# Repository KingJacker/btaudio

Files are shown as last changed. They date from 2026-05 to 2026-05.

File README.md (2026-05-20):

# btaudio — Audiophiles Bluetooth 5.1 Upgrade-Board für Kopfhörer

Ein kompromissloses Wireless-Upgrade-Modul für Kabelkopfhörer. Kein All-in-One-Kompromiss — stattdessen drei dedizierte Stufen für maximale Klangqualität ohne Hintergrundrauschen.

## Architektur

```
QCC5125 (BT 5.1)  →[I2S]→  PCM5102A (DAC)  →[Analog]→  TPA6132A2 (Amp)  →  Kopfhörer
   Empfang                    Wandlung                     Verstärkung
```

**Stufe 1 — Empfang:** QCC5125 empfängt High-Res-Audio via aptX HD / LDAC und gibt das Signal rein digital (I2S) weiter. Keine Funkstörungen im Analogpfad.

**Stufe 2 — Wandlung:** PCM5102A (High-End-DAC) wandelt das I2S-Signal in ein sauberes analoges Audiosignal. Dedizierter Chip statt integriertem DAC-Billigst-Lösung.

**Stufe 3 — Verstärkung:** TPA6132A2 treibt die Kopfhörer direkt an ("Capless"-Design) — keine Elektrolytkondensatoren im Signalweg, die den Klang verfärben.

## Schaltplan

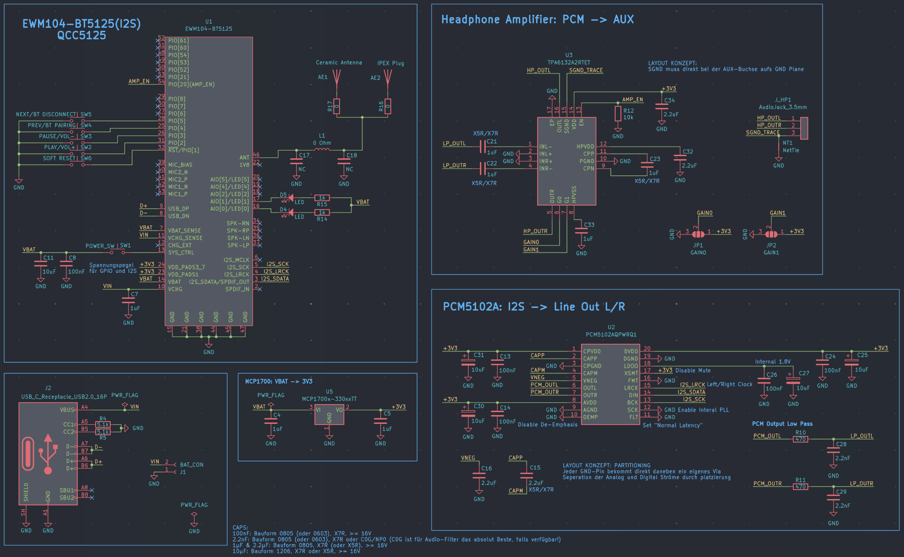
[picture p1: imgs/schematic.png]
Schaltplan


## Platine (3D-Ansicht)

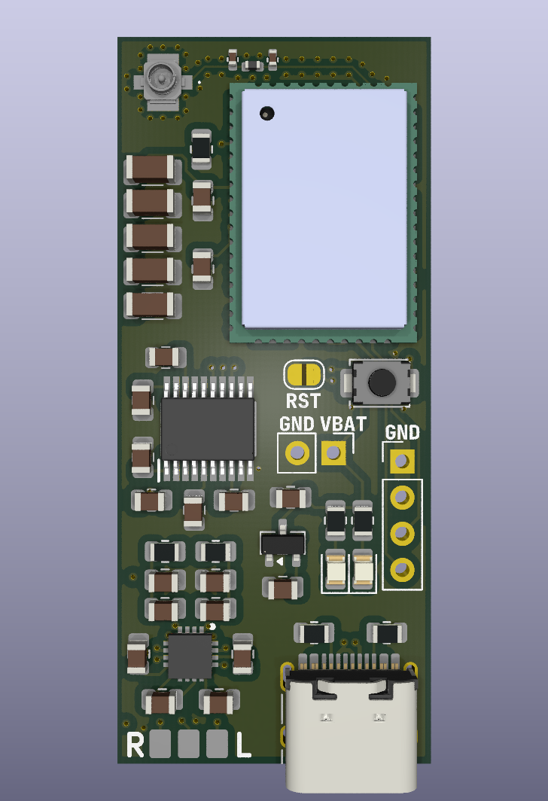
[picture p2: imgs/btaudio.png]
PCB 3D-Render


## Ziel

Alte, hochwertige Kabelkopfhörer auf modernes audiophiles Bluetooth-Niveau heben — durch konsequente Trennung von Funk, DA-Wandlung und Verstärkung.

## Hardware

- **BT-Modul:** Qualcomm QCC5125 (Bluetooth 5.1, aptX HD, LDAC)
- **DAC:** Texas Instruments PCM5102A
- **Amp:** Texas Instruments TPA6132A2 (Capless Headphone Amp)
- **Design-Tool:** KiCad

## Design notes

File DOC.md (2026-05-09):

***

# Projekt-Dokumentation: Audiophiles Bluetooth 5.1 Kopfhörer-Modul

## 1. Projektübersicht & Architektur
Das Ziel dieses Projekts ist die Entwicklung eines eigenen Carrier-Boards (Trägerplatine), um einen alten Kopfhörer mit modernem Bluetooth 5.1 auszustatten. Anstatt diskrete Bluetooth-SoCs zu verwenden (die oft hinter NDAs versteckt oder schwer zu löten sind), wird ein **System-on-Module (SoM)** Ansatz gewählt.

Um die höchste Audioqualität ohne störendes Hintergrundrauschen (oft durch das RF-Signal verursacht) zu erreichen, nutzt das Design eine strikt getrennte, audiophile Architektur:
**Bluetooth-Modul (Digital I2S) $\rightarrow$ Separater I2S-DAC $\rightarrow$ Dedizierter Kopfhörerverstärker.**

## 2. Die Wahl des Bluetooth-Moduls: EBYTE EWM104-BT5125(I2S)
Nach der Analyse des Datenblattes fiel die Wahl auf das EBYTE-Modul basierend auf dem **Qualcomm QCC5125** Chip.
*   **Warum QCC5125?** Unterstützt echtes Stereo, Bluetooth 5.1 und High-End-Codecs wie aptX-HD und LDAC. (Der günstigere QCC3040 ist bei diesem Hersteller nur für Mono/TWS konfiguriert).
*   **Warum die I2S-Variante?** Das Modul gibt ein rein digitales I2S-Signal aus. Die (DAC)-Variante des Moduls würde ein differentielles Analogsignal ausgeben, was zwingend einen externen Differenzverstärker erfordern würde und anfälliger für Rauschen ist.
*   **Vorteil:** Das Modul bringt bereits einen Laderegler für den Li-Po-Akku mit!

## 3. Die drei Kern-Blöcke der Schaltung

### 3.1 Die Audio-Stufe ("DirectPath / Capless")
*   **DAC (TI PCM5102A):** Wandelt das digitale I2S-Signal in ein sauberes analoges Line-Signal. Generiert seinen Systemtakt (MCLK) intern und benötigt nur wenige externe Bauteile.
*   **Verstärker (TI TPA6132A2 / MAX97220):** Liefert den nötigen Strom für typische 32-Ohm Kopfhörertreiber, um einen satten Bass zu garantieren.
*   *Architektur-Vorteil:* Beide ICs besitzen interne Charge-Pumps zur Erzeugung einer negativen Versorgungsspannung. Dadurch entfallen große DC-Blocking-Kondensatoren am Audioausgang, die den Klang verfälschen würden.

### 3.2 Stromversorgung & USB-C
*   Der Akku wird direkt an den `VBAT`-Pin des EBYTE-Moduls angeschlossen.
*   Die 5V-Spannung der USB-C Buchse geht an den `VCHG`-Pin des Moduls (internes BMS lädt den Akku).
*   Für die modernen USB-C Power Delivery Netzteile müssen die Pins `CC1` und `CC2` der Buchse über jeweils einen **$5.1\,\text{k}\Omega$ Widerstand auf GND** gezogen werden.
*   Ein extrem rauscharmer LDO-Regler macht aus der schwankenden Akkuspannung (3.0 - 4.2V) perfekte **3.3V** für den Audio-DAC und den Verstärker.

### 3.3 Hochfrequenz (RF) & Antennendesign
Das EBYTE-Modul besitzt keine integrierte Antenne (Stamp-Hole).
*   Vom Modul-Pin `ANT` wird eine exakt **$50\,\Omega$ impedanzkontrollierte Leiterbahn** zu einer SMD-Keramikantenne geroutet.
*   In Serie wird ein $0\,\Omega$ Widerstand als Brücke / Platzhalter für ein mögliches Matching-Netzwerk platziert.

---

## 4. Bill of Materials (BOM) / Stückliste

| Kategorie | Bauteil / Funktion | Empfohlene(r) Typ(en) / Partnummer | Bauform | Stk. | Anmerkung / Aufgabe im Schaltplan |
| :--- | :--- | :--- | :--- | :--- | :--- |
| **Funk / Core** | **Bluetooth SoM** | EBYTE EWM104-BT5125(I2S) | Stamp Hole | 1 | Das Gehirn; liefert digitales Audio (I2S) & lädt den Akku. |
| | **Keramik-Antenne** | Johanson 2450AT18A100E *oder* Yageo | SMD 0603/1206 | 1 | 2.4 GHz Chip-Antenne (vermeidet komplexes PCB-Antennendesign). |
| | **RF-Matching** | $0\,\Omega$ Widerstand | SMD 0603 | 1 | Brücke in Serie zwischen Modul-Pin `ANT` und Antenne. |
| **Audio** | **I2S Audio-DAC** | **Texas Instruments PCM5102A** | TSSOP-20 | 1 | Wandelt I2S (digital) exzellent in analoges Line-Signal um. |
| | **Kopfhörer-Amp** | **TI TPA6132A2** *oder* **Maxim MAX97220** | WQFN / TDFN | 1 | Capless-Verstärker; liefert den nötigen Strom für satte Bässe. |
| | **Audio-Buchse** | 3.5mm Klinkenbuchse (z.B. PJ-320D) | SMD oder THT | 1 | Optional; Kopfhörerkabel können auch direkt verlötet werden. |
| **Power** | **USB-C Buchse** | 6-Pin oder 16-Pin Type-C | SMD | 1 | Ladeanschluss; 5V gehen an Pin 10 (`VCHG`) des Moduls. |
| | **PD-Widerstände** | $5.1\,\text{k}\Omega$ Widerstand | SMD 0603 | 2 | Zwingend an `CC1` & `CC2` (gegen GND) für USB-C Erkennung. |
| | **Li-Po Akku** | 3.7V, ca. 300 - 500 mAh mit BMS | JST-Stecker | 1 | Spannungsquelle; an Pin 14 (`VBAT`) und `GND`. |
| | **3.3V LDO-Regler** | TI TPS7A2033 *oder* MIC5219-3.3YM5 | SOT-23-5 | 1 | Rauscharme 3.3V für DAC, Amp & IO-Signale. |
| **Interface** | **Taster**| Standard Tactile Switch (Drucktaster) | SMD | 4 | Play/Pause, Vol+, Vol- und Power/Pairing. |
| | **Status LEDs** | LED Rot & LED Blau | SMD 0603 | 2 | Für Systemstatus. |
| | **LED-Widerstände** | ca. $470\,\Omega$ bis $1\,\text{k}\Omega$ | SMD 0603 | 2 | Strombegrenzung für die LEDs. |
| **Passiv*** | **Kondensatoren 1** | $100\,\text{nF}$ ($0.1\,\mu\text{F}$), MLCC, X5R/X7R | SMD 0603 | ~ 8 | Decoupling: Jeder IC braucht einen nah am VCC-Pin! |
| | **Kondensatoren 2** | $1\,\mu\text{F}$ und $2.2\,\mu\text{F}$, MLCC, X5R/X7R | SMD 0603 | ~ 5 | Für die internen Charge-Pumps von DAC und Verstärker. |
| | **Kondensatoren 3** | $10\,\mu\text{F}$, MLCC, X5R/X7R | SMD 0603 | ~ 3 | Ein- und Ausgang des 3.3V LDO-Reglers. |

*\*Tipp: Standard R/C-Bauteile am besten als komplettes "0603 SMD Resistor/Capacitor Book" bestellen.*

---

## 5. Goldene Regeln für das PCB-Layout

1.  **Kupferfreie Zone (Antenne):** Weder auf dem Top-Layer noch auf den inneren Lagen oder dem Bottom-Layer darf Kupfer (weder Masse noch Signale) unter der Antenne verlaufen. Am besten platziert man die Keramikantenne ganz am Rand der Platine ("Overhang").
2.  **Massekonzept (Grounding):** Es handelt sich um ein Mixed-Signal-Board. Halte den digitalen Funkt-Teil (Bluetooth) physisch auf der Leiterplatte getrennt vom analogen Teil (DAC-Ausgang & Verstärker). Achte auf eine solide und durchgängige Massefläche (Ground Plane) für den HF-Teil.
3.  **Decoupling:** Die $100\,\text{nF}$ Kondensatoren müssen so nah wie physikalisch möglich an die Versorgungspins (VCC/VDD) der jeweiligen ICs platziert werden.
4.  **Lötbarkeit:** Das EBYTE-Modul (Stamp-Hole), TSSOP und SOT-23 lassen sich von Hand mit dem Lötkolben löten. Für QFN-Packages (Verstärker) wird **Lötpaste und Heißluft** (Hot Air Station) benötigt.

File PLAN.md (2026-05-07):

# btaudio Schematic Plan

Bluetooth headphone adapter. Phone pairs over BT → QCC5125 decodes → I2S → PCM5102A DAC → TPA6132A2 headphone amp → 3.5mm jack.

---

## Parts

| Ref | Part | Role |
|-----|---|---|
| U1 | EWM104-BT5125 (I2S variant) | BT5.1 receiver, I2S master |
| U2 | PCM5102AQPWRQ1 | I2S DAC, stereo audio out |
| U3 | TPA6132A2RTET | DirectPath headphone amp |
| U4 | 3.3V LDO (e.g. MCP1700-3302E) | Vbat → 3.3V |
| J1 | 3.5mm TRS jack | Headphone output |
| J2 | Battery connector | LiPo cell (external) |
| — | Charging board (MCP73871) | Already designed separately |

---

## Power Architecture

```
USB-C ──► Vin (5V) ──► MCP73871 charging board ──► Vbat (3.7–4.2V LiPo)
                │                                         │
                │                                         ▼
                │                                    LDO (U4)
                │                                         │
                │                                         ▼
                │                                      3V3 rail
                │
                └──► U1 VCHG (pin 10)   [charger input, 4–6.5V]

Vbat ──► U1 VBAT (pin 14)              [module battery supply]
3V3  ──► U1 VDD_PADS1 (pin 23)         [PIO bank 1 logic voltage]
3V3  ──► U1 VDD_PADS3_7 (pin 24)       [PIO bank 3–7 logic voltage]
3V3  ──► U2 AVDD, DVDD, CPVDD
3V3  ──► U3 VDD, HPVDD
```

**Decoupling:** 100nF + 10µF on each supply rail at each IC.

**Note:** U1 pin 22 (1V8 output) — leave available as test point; not used to power VDD_PADS (keep both banks at 3.3V so I2S signals are 3.3V compatible with PCM5102A).

---

## I2S Signal Chain

```
U1 EWM104-BT5125          U2 PCM5102A
─────────────────          ───────────
I2S_SCK   (pin 5)  ──────► BCK  (pin 13)   bit clock
I2S_LRCK  (pin 4)  ──────► LRCK (pin 15)   LR clock
I2S_SDATA (pin 3)  ──────► DIN  (pin 14)   data
I2S_MCLK  (pin 6)  ──────► SCK  (pin 12)   system clock
```

---

## Audio Chain

```
U2 PCM5102A                          U3 TPA6132A2
───────────                          ────────────
OUTL (pin 6) ──[1µF]──────────────► INL+ (pin 2)
                                     INL- (pin 1) ── GND

OUTR (pin 7) ──[1µF]──────────────► INR+ (pin 3)
                                     INR- (pin 4) ── GND

                         U3 TPA6132A2              J1 3.5mm
                         ────────────              ────────
                         OUTL (pin 16) ───────────► L
                         OUTR (pin 5)  ───────────► R
                         HPVSS/PGND/SGND/EP ──────► GND sleeve
```

AC coupling caps (1µF) between PCM5102A and TPA6132A2 needed because PCM5102A uses internal charge pump; output may not be exactly 0V DC.

**TPA6132A2 gain:** G0 (pin 6) and G1 (pin 7) set gain:
- 00 = 6dB, 01 = 12dB, 10 = 18dB, 11 = 24dB
- Start with 01 (12dB). G0 and G1 can be jumper-selectable or tied.

**TPA6132A2 enable:** EN (pin 13) — pull high (3V3) through resistor. Could tie to a PIO for soft mute.

**PCM5102A control pins:**
| Pin | Name | Connect |
|-----|---|---|
| 10 | DEMP | GND (no de-emphasis) |
| 11 | FLT | GND (normal latency filter) |
| 16 | FMT | GND (I2S format, left-justified on high) |
| 17 | XSMT | 3V3 (unmuted); or drive from PIO for soft-mute |
| 18 | LDOO | 100nF to GND (internal LDO bypass) |

---

## SYS_CTRL Circuit (U1 pin 13)

Datasheet warning: cannot pull directly to VBAT. Need delay circuit after power-on.

```
Vbat ──[R 100k]──┬── MOSFET gate
                 │
                [C 10µF]
                 │
                GND

MOSFET drain → SYS_CTRL (pin 13)
MOSFET source → GND
```

RC time constant ~1s delay before SYS_CTRL asserts. Use N-channel MOSFET (e.g. 2N7002).
Add a parallel tactile button (RESET# / manual power-on) from SYS_CTRL to GND.

---

## PIO / Button Assignments (default firmware)

| PIO | Pin | Function | Circuit |
|-----|-----|---|---|
| PIO[2] | 31 | Play / Vol+ | Tactile SW to GND, 10k pull-up to 3V3 |
| PIO[3] | 26 | Pause / Vol- | Tactile SW to GND, 10k pull-up to 3V3 |
| PIO[4] | 25 | Prev / BT pair | Tactile SW to GND, 10k pull-up to 3V3 |
| PIO[5] | 28 | Next / BT disc | Tactile SW to GND, 10k pull-up to 3V3 |
| PIO[20] | 54 | Amp enable | Tie to TPA6132A2 EN (via 10k) |
| PIO[21] | 53 | LED indicator | LED + 330R to GND |
| PIO[52] | 50 | LED indicator | LED + 330R to GND |

---

## LED Assignments

| Pin | Name | Function |
|-----|---|---|
| 16 | AIO[0]/LED[0] | Status LED (power on, pairing, etc.) |
| 17 | AIO[1]/LED[1] | Second LED (optional) |

Open-drain outputs — connect LED anode to 3V3 through resistor, cathode to pin.

---

## Antenna

Pin 46 (ANT): 50Ω impedance. Either:
- PCB trace antenna (already on module — no external connection needed for onboard antenna)
- Or route to SMA connector through 50Ω trace for external antenna

Check module variant: EWM104-BT5125(I2S) has PCB trace antenna built in. If so, pin 46 may be NC or connect to a test point only.

---

## USB (pins 8, 9)

USB_DN (pin 8), USB_DP (pin 9): full-speed USB for firmware/configuration.
- Optional: break out to USB-C connector for debug/config access
- Not required for normal operation

---

## GND Pins

Pins 15, 21, 38, 44, 45, 47 — all connect to GND plane.

---

## Schematic Sheets (proposed)

| Sheet | Contents |
|---|---|
| Root | Block diagram, power connectors, inter-sheet refs |
| Power | LDO, decoupling, power rails, battery interface |
| BT Module | U1 with all pin connections |
| Audio | U2 (PCM5102A) + U3 (TPA6132A2) + J1 |
| Control | Buttons, LEDs, SYS_CTRL delay circuit |

---

## Finalized Decisions

| # | Decision |
|---|---|
| 1 | **Single sheet** — enlarge sheet size later as needed |
| 2 | **MCP1700-3302E** LDO (low Iq ~1.6µA, good for battery life, SOT-23) |
| 3 | **USB debug exposed** — USB_DN/DP break out to USB-C or micro-USB connector |
| 4 | **TPA6132A2 gain: solder-tie G0/G1** — add schematic note "resolder to change gain" |
| 5 | **MIC inputs: all NC** — headphone-only use case |
| 6 | **SMD ceramic chip antenna** — Johanson 0433AT62A0020E (2.4GHz, 50Ω, 3.2×1.6mm) |

---

## Antenna Detail

Module ANT pin (46) is the RF port — module has no built-in antenna.

```
U1 ANT (pin 46) ──[50Ω trace]──► π matching network ──► Johanson 0433AT62A0020E
```

π matching network (tune at layout stage based on PCB stackup):
- Series inductor + shunt caps either side (typical: 2.2nH series, 1pF shunt)
- Leave footprints populated with 0Ω/DNP for tuning
- Ground clearance required under antenna (no copper pour under chip antenna element)

---

## Schematic Notes to Add

- Near TPA6132A2 gain pins: *"G0/G1 soldered for 12dB gain. Reflow to change: 00=6dB 01=12dB 10=18dB 11=24dB"*
- Near SYS_CTRL: *"RC delay ~1s. Do not pull directly to VBAT."*
- Near MIC pins: *"MIC1/MIC2 inputs NC — headphone-only build"*
- Near antenna: *"Tune π network for PCB stackup. No copper under antenna element."*

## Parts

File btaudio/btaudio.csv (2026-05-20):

Id | Designator | Footprint | Quantity | Designation | Supplier and ref
1 | AE2 | A1JB | 1 | IPEX Plug
2 | C4, C5, C7, C21, C22, C23, C33 | C_0805_2012Metric | 7 | 1uF
3 | C8, C13, C14, C24, C26 | C_0805_2012Metric | 5 | 100nF
4 | C11, C25, C27, C30, C31 | C_1206_3216Metric | 5 | 10uF
5 | C15, C16, C32, C34 | C_0805_2012Metric | 4 | 2.2uF
6 | C17, C18 | C_0402_1005Metric | 2 | NC
7 | C28, C29 | C_0805_2012Metric | 2 | 2.2nF
8 | D4, D5 | LED_0805_2012Metric | 2 | LED
9 | J1 | PinHeader_1x04_P2.54mm_Vertical | 1 | BTNS
10 | J2 | USB_C_Receptacle_HRO_TYPE-C-31-M-12 | 1 | USB_C_Receptacle_USB2.0_16P
11 | J3 | aux-pads | 1 | Audio
12 | J6 | PinHeader_1x02_P2.54mm_Vertical | 1 | Battery
13 | L1 | L_0402_1005Metric | 1 | 0 Ohm
14 | R4, R5 | R_0805_2012Metric | 2 | 5.1k
15 | R10, R11 | R_0805_2012Metric | 2 | 470
16 | R12 | R_0805_2012Metric | 1 | 10k
17 | R14, R15 | R_0805_2012Metric | 2 | 1k
18 | SW1 | SW_SPST_TS-1088-xR020 | 1 | POWER_SW
19 | SW6 | SolderJumper-2_P1.3mm_Open_RoundedPad1.0x1.5mm | 1 | SOFT RESET
20 | U1 | EWM104-BT5125(KiCAD)_flipped_nonhole | 1 | EWM104-BT5125
21 | U2 | SOP65P640X120-20N | 1 | PCM5102AQPWRQ1
22 | U3 | QFN50P300X300X80-17N-D | 1 | TPA6132A2RTET
23 | U5 | SOT-23 | 1 | MCP1700x-330xxTT

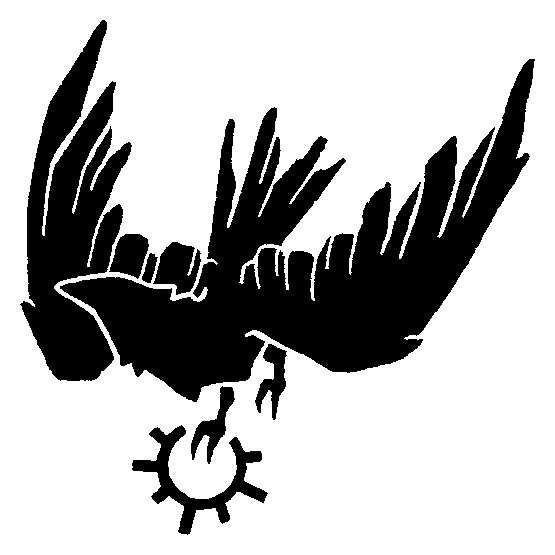
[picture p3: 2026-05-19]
parts/raven_with_sun_silkscreen.png

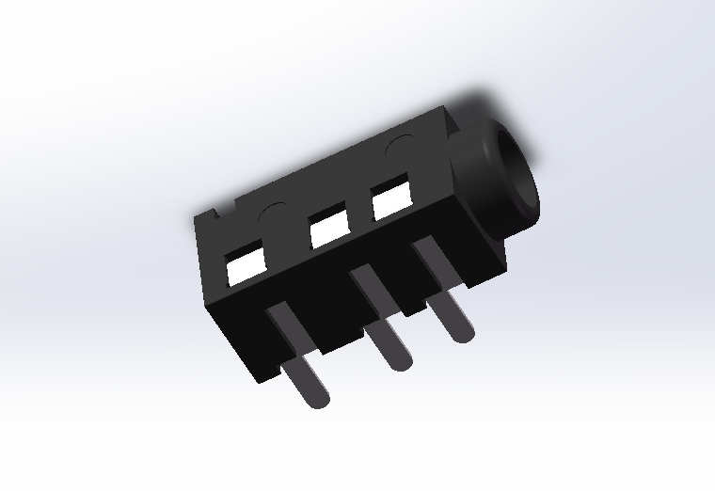
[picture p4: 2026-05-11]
parts/pj320a-pj320d-3-5mm-jack/QQ20210410181939.png

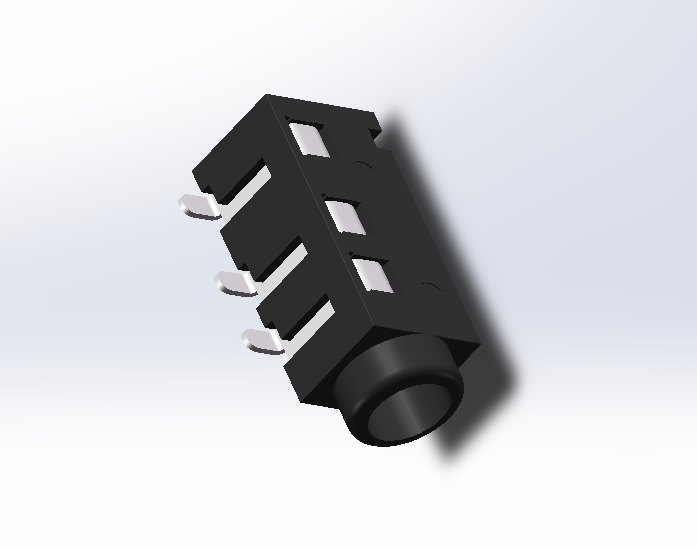
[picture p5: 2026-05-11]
parts/pj320a-pj320d-3-5mm-jack/QQ20210410182026.png

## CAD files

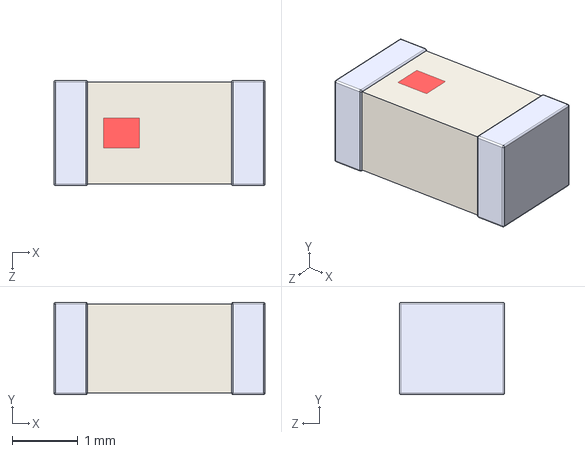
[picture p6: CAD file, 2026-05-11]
parts/2450AT18A0100001E/3D/2450AT18A0100001E.stp
3.20 x 1.40 x 1.60 mm

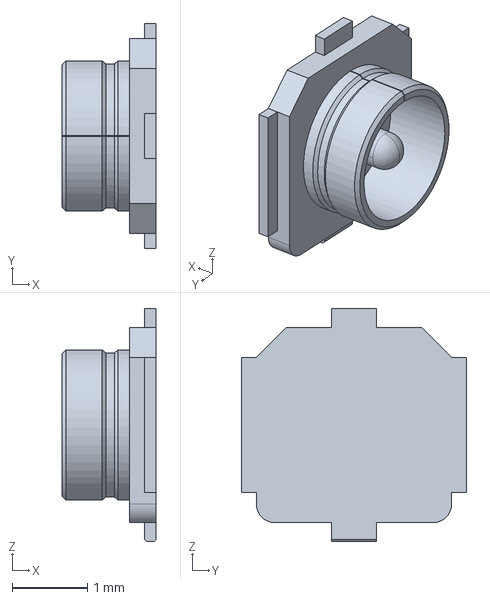
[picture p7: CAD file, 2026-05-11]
parts/A-1JB/3D/A-1JB.stp
1.25 x 3.00 x 3.10 mm

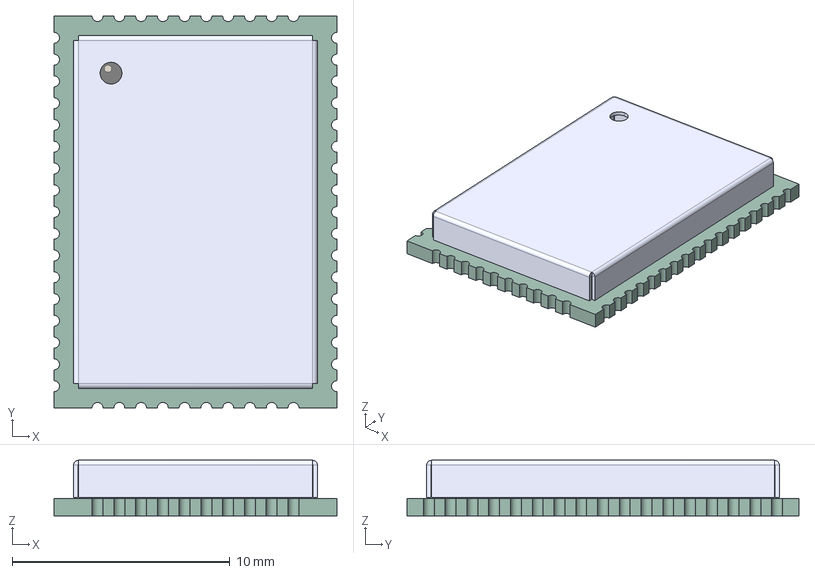
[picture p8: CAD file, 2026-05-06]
parts/EWM104-BT5125-PCB/EWM104-BT5125-3D/EWM104-BT5125-3D/EWM104-BT5125.step
13.0 x 18.0 x 2.55 mm
C_0402_1005Metric x 17
A_FV1206
BGA_100_110x110mm_Layout10x10_P10mm_Ball05mm_Pad04mm_NSMD
PBZ-208
C_0201_0603Metric
R_0402_1005Metric x 2
Texas_R-PUSON-N8_USON-8-1EP_1.6x2.1mm_P0.5mm_EP0.40x1.7mm
R_0201_0603Metric
_autosave-10826-V1.0_PCB

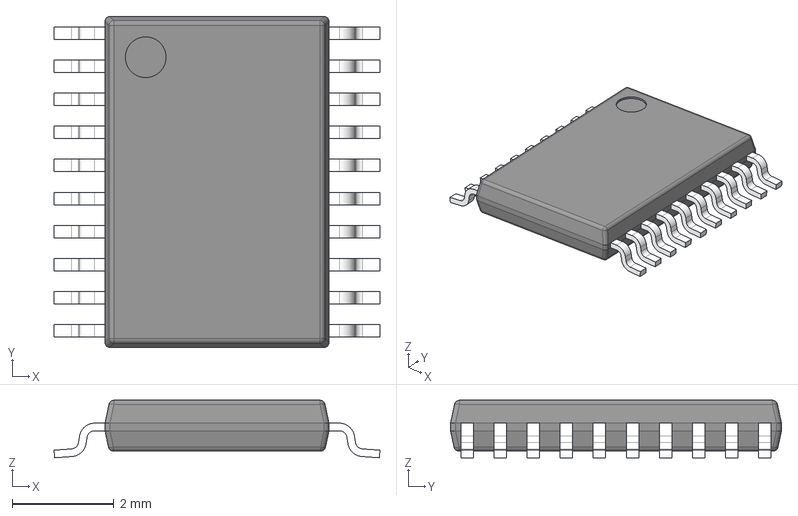
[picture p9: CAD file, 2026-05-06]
parts/PCM5102AQPWRQ1/3D/PCM5102AQPWRQ1.stp
6.40 x 6.50 x 1.13 mm
BODY-TSSOP
LEAD-TSSOP x 20
PIN1

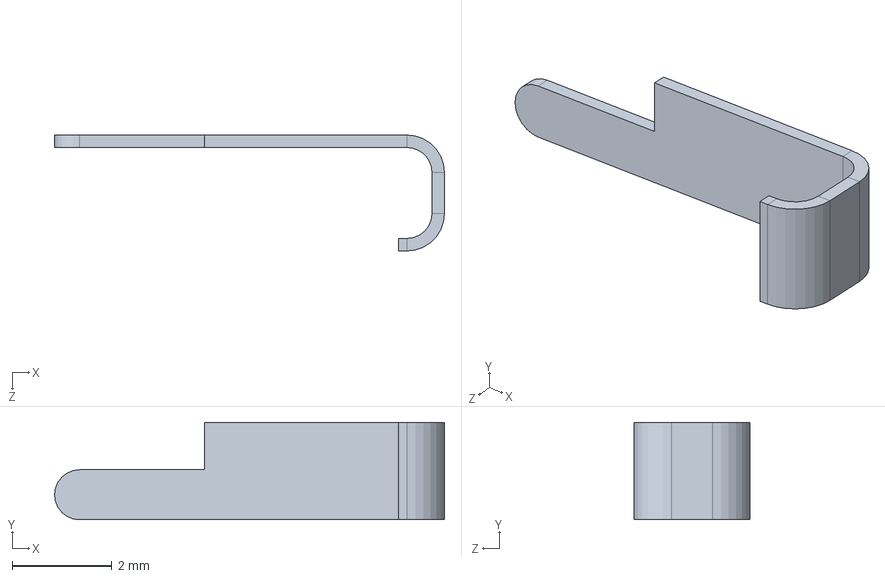
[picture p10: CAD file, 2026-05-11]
parts/pj320a-pj320d-3-5mm-jack/PJ320A/PJ320A-Pin.SLDPRT
7.80 x 1.95 x 2.32 mm

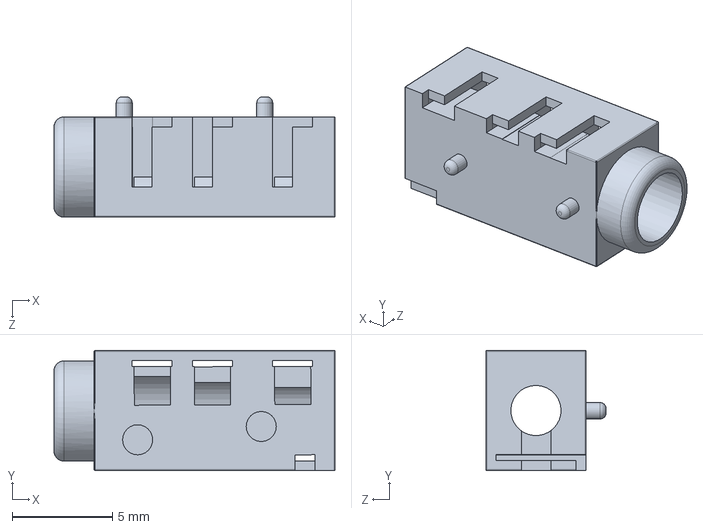
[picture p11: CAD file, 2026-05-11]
parts/pj320a-pj320d-3-5mm-jack/PJ320D/PJ320A.SLDPRT
14.0 x 6.00 x 6.00 mm

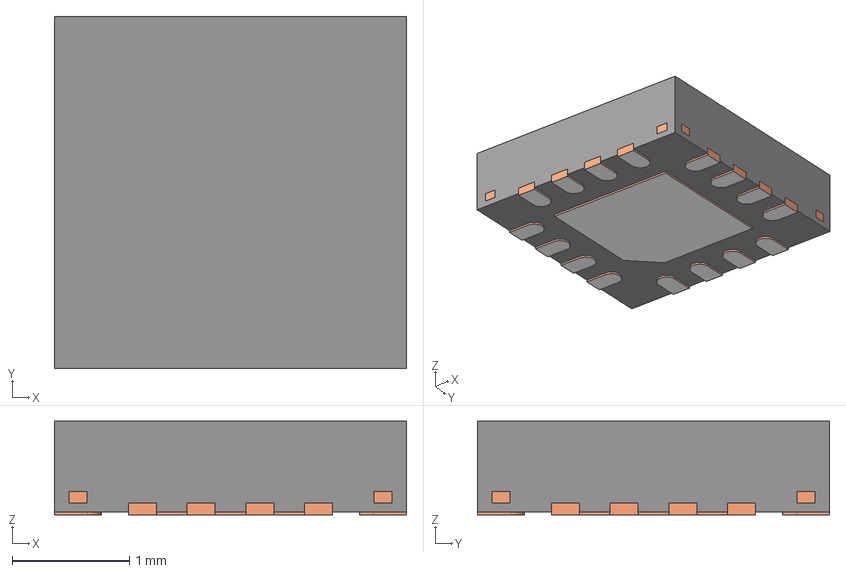
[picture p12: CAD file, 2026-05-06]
parts/TPA6132A2RTET/3D/TPA6132A2RTET.stp
3.00 x 3.00 x 0.8 mm
BODY-QFN
FRAME-RTE0016C
PIN1-ID

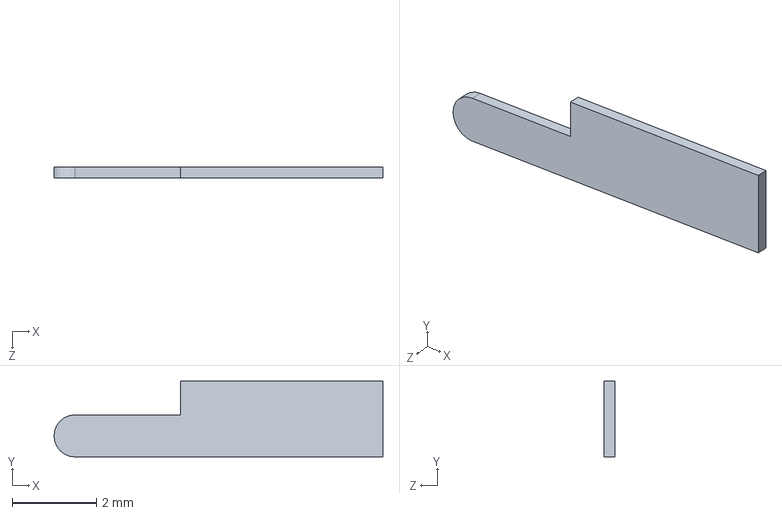
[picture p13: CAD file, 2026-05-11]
parts/pj320a-pj320d-3-5mm-jack/PJ320A/PJ320A-Pin-B.SLDPRT
7.80 x 1.80 x 0.25 mm

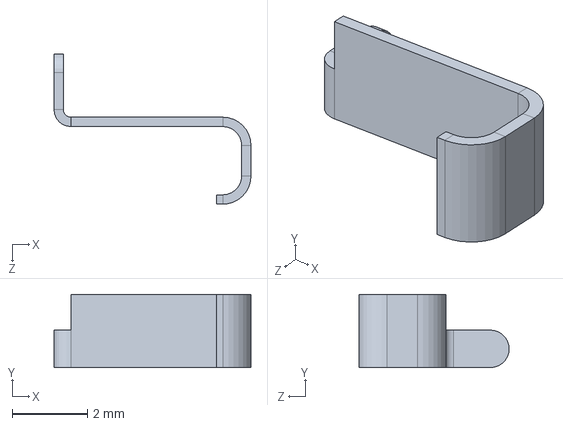
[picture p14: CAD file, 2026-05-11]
parts/pj320a-pj320d-3-5mm-jack/PJ320D/PJ320D-Pin.SLDPRT
5.25 x 1.95 x 4.01 mm

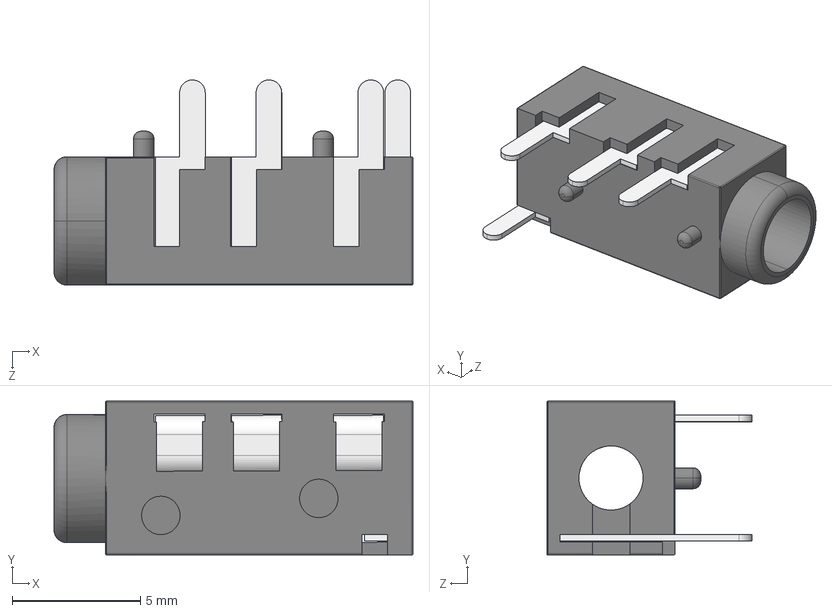
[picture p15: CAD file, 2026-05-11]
parts/pj320a-pj320d-3-5mm-jack/PJ320A/PJ320A.STEP
14.0 x 6.00 x 8.00 mm
PJ320A
PJ320A-Pin x 3
PJ320A-Pin-B

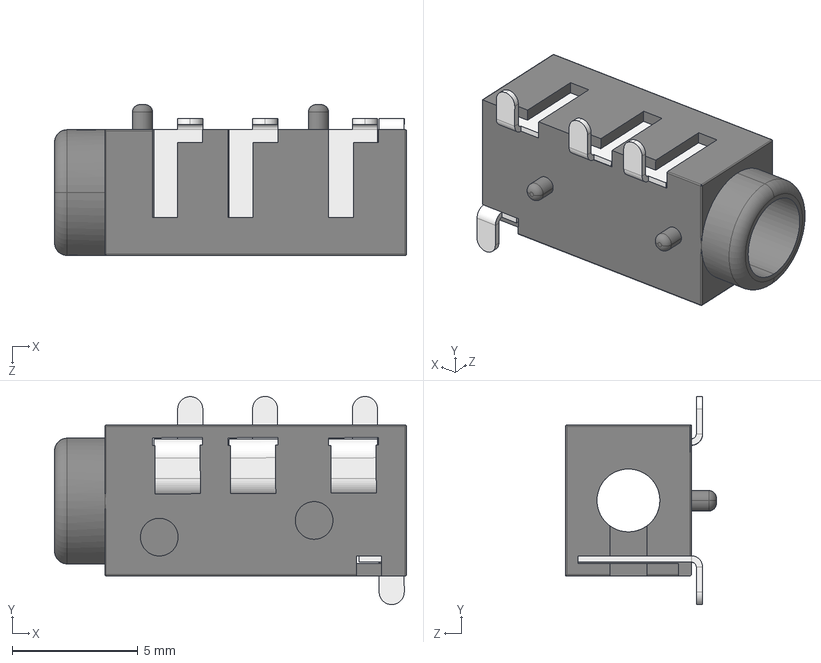
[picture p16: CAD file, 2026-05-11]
parts/pj320a-pj320d-3-5mm-jack/PJ320D/PJ320D.STEP
14.0 x 8.28 x 6.00 mm
PJ320A
PJ320D-Pin x 3
PJ320D-Pin-B

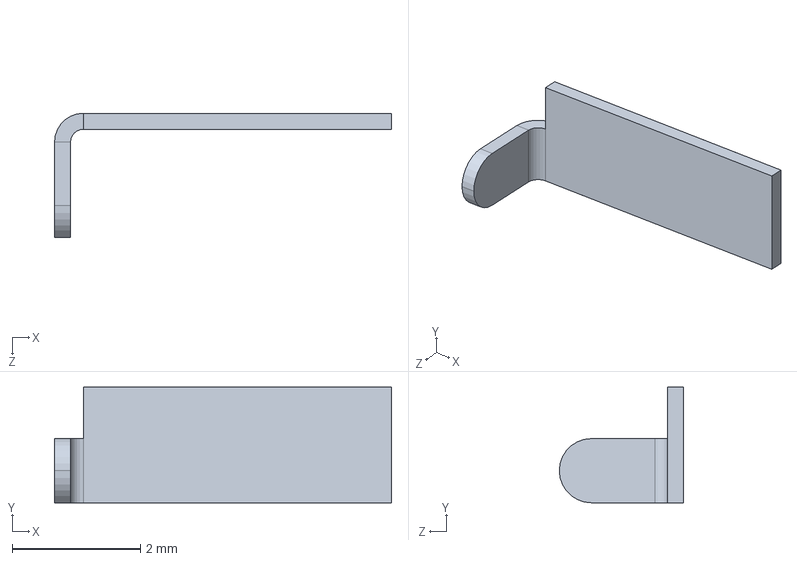
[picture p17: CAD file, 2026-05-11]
parts/pj320a-pj320d-3-5mm-jack/PJ320D/PJ320D-Pin-B.SLDPRT
5.25 x 1.80 x 1.94 mm

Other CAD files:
parts/pj320a-pj320d-3-5mm-jack/PJ320A/PJ320A.SLDASM
parts/pj320a-pj320d-3-5mm-jack/PJ320D/PJ320D.SLDASM

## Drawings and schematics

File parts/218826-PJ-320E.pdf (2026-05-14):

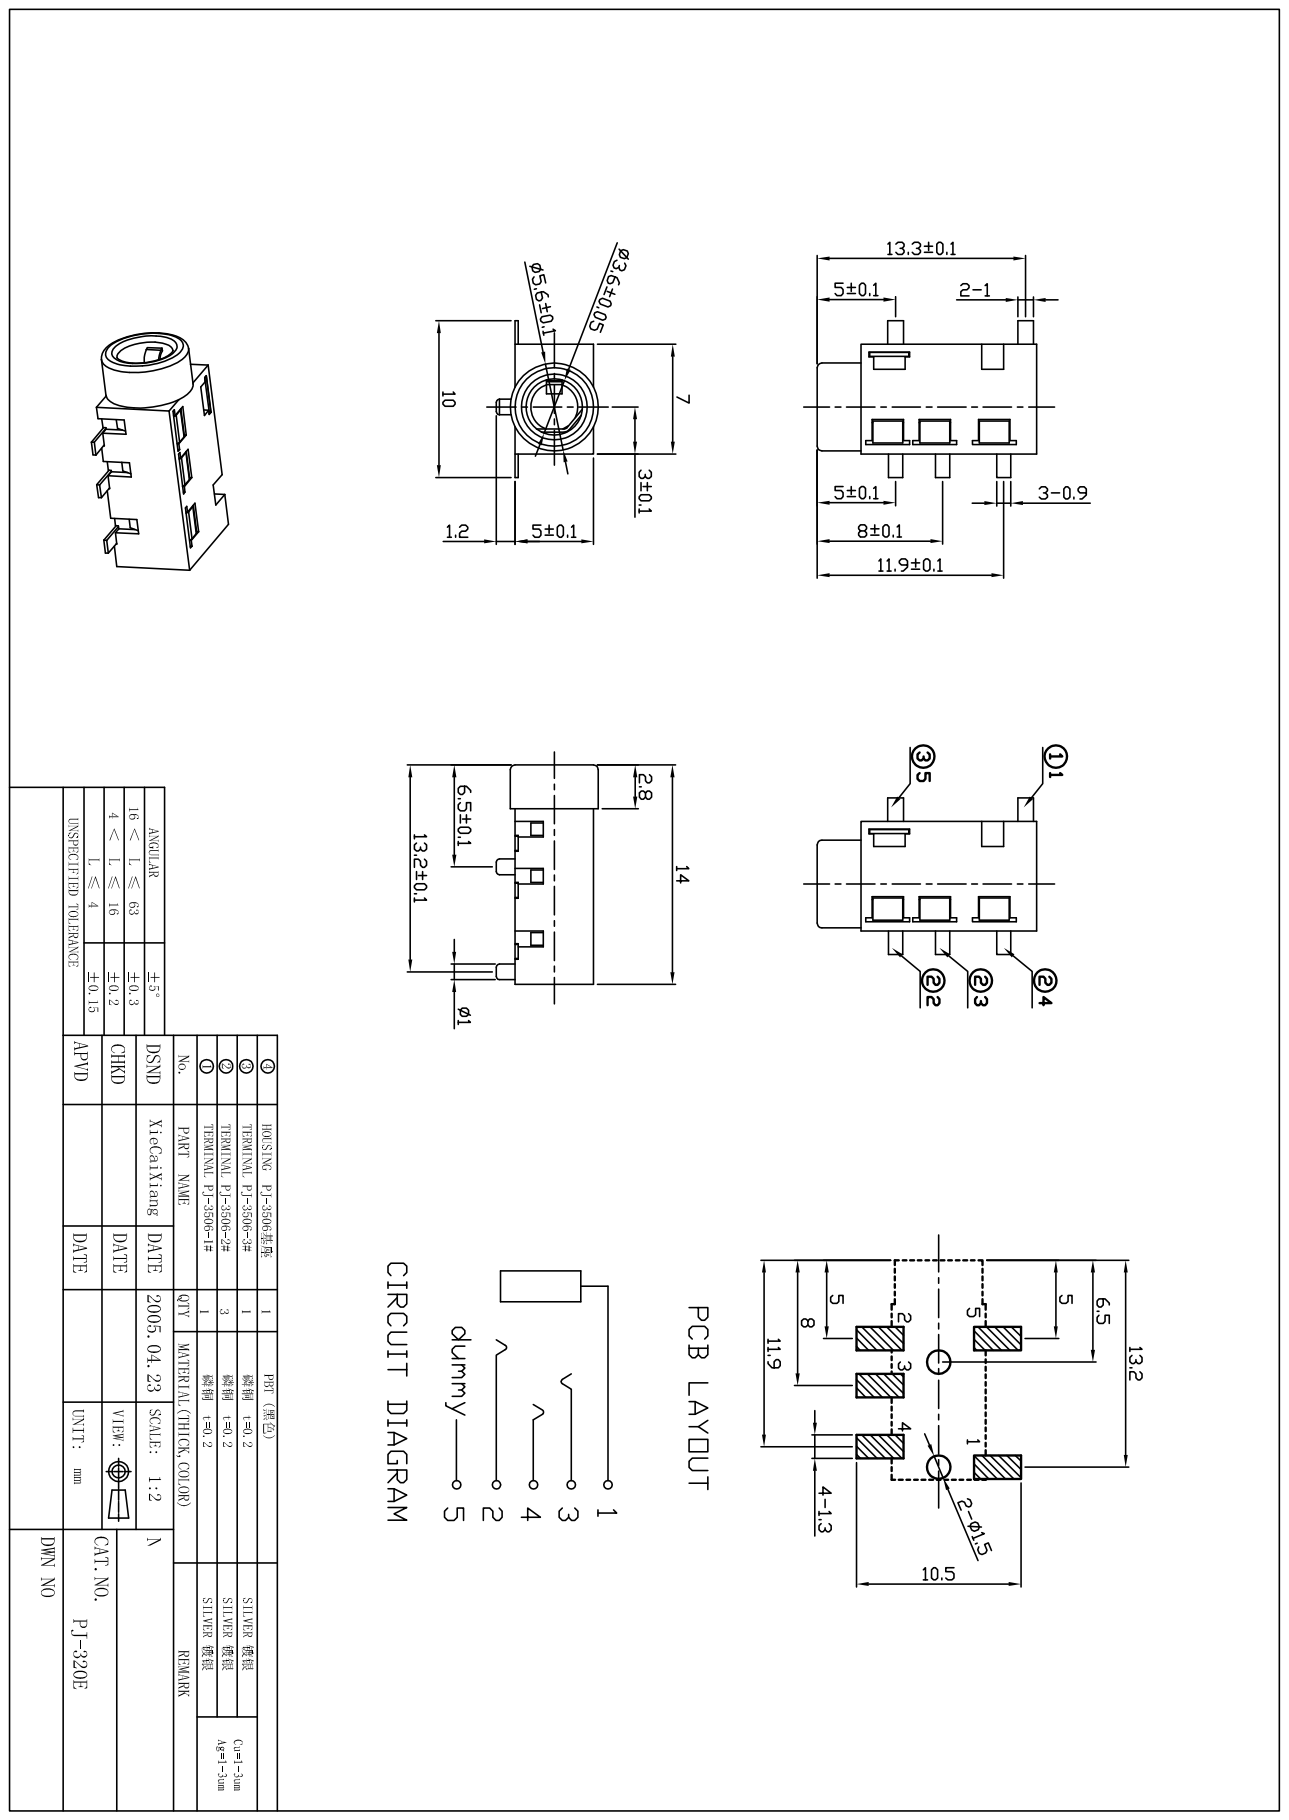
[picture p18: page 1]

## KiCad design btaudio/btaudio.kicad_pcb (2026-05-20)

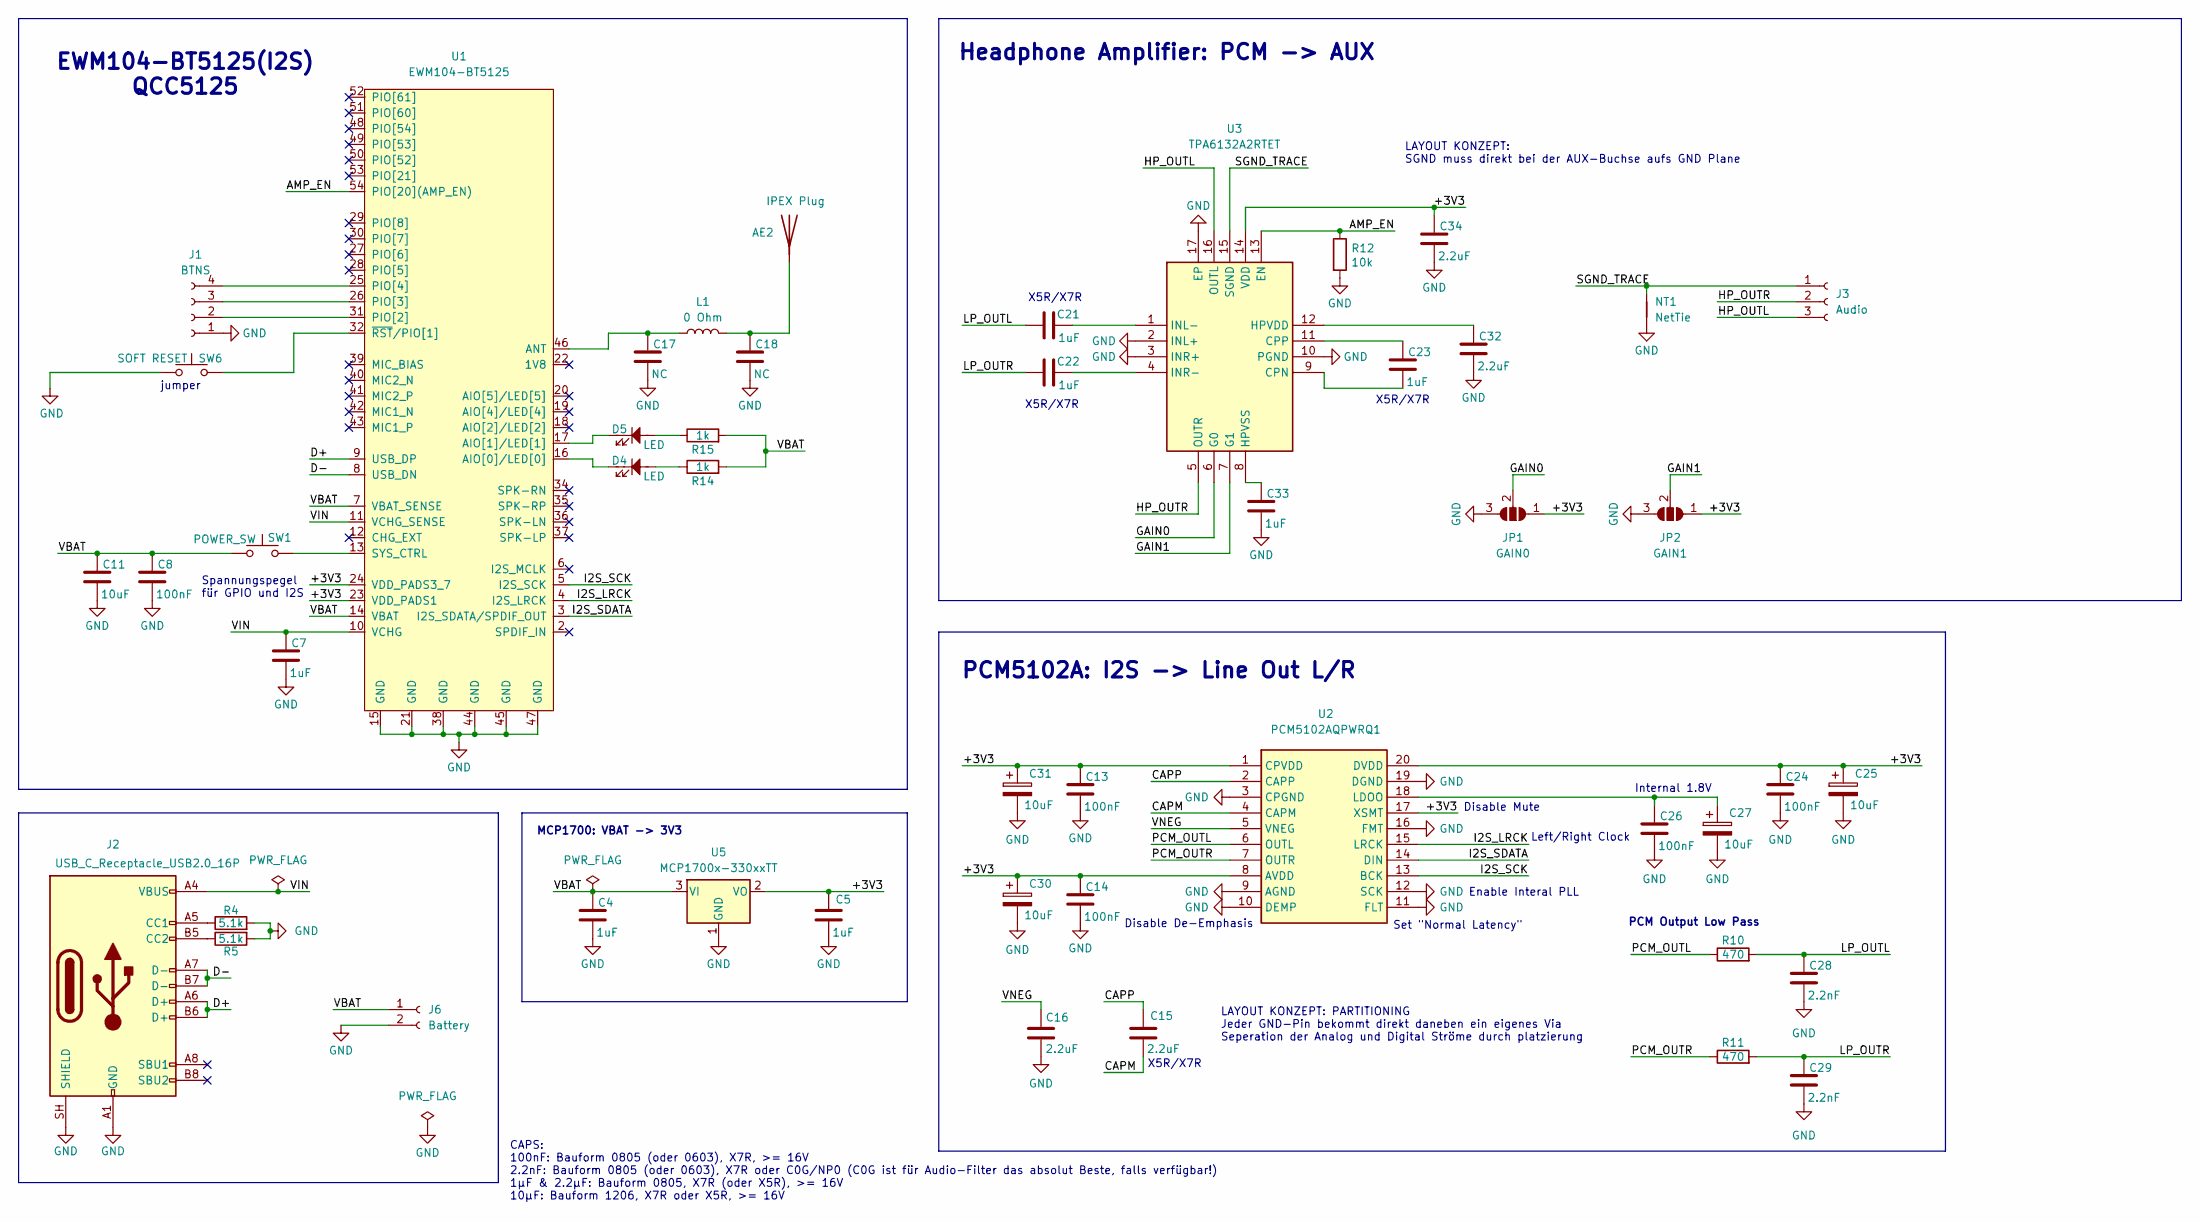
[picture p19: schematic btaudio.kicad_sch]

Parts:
AE2: IPEX Plug; A1JB
C4, C5, C7, C21, C22, C23, C33: 1uF; C_0805_2012Metric
C8, C13, C14, C24, C26: 100nF; C_0805_2012Metric
C11, C25, C27, C30, C31: 10uF; C_1206_3216Metric
C15, C16, C32, C34: 2.2uF; C_0805_2012Metric
C17, C18: NC; C_0402_1005Metric
C28, C29: 2.2nF; C_0805_2012Metric
D4, D5: LED; LED_0805_2012Metric
J1: BTNS; PinHeader_1x04_P2.54mm_Vertical
J2: USB_C_Receptacle_USB2.0_16P; USB_C_Receptacle_HRO_TYPE-C-31-M-12
J3: Audio; aux-pads
J6: Battery; PinHeader_1x02_P2.54mm_Vertical
JP1: GAIN0; SolderJumper-3_P1.3mm_Open_RoundedPad1.0x1.5mm
JP2: GAIN1; SolderJumper-3_P1.3mm_Open_RoundedPad1.0x1.5mm
L1: 0 Ohm; L_0402_1005Metric
NT1: NetTie; NetTie-2_SMD_Pad0.5mm
R4, R5: 5.1k; R_0805_2012Metric
R10, R11: 470; R_0805_2012Metric
R12: 10k; R_0805_2012Metric
R14, R15: 1k; R_0805_2012Metric
SW1: POWER_SW; SW_SPST_TS-1088-xR020
SW6: SOFT RESET; SolderJumper-2_P1.3mm_Open_RoundedPad1.0x1.5mm
U1: EWM104-BT5125; EWM104-BT5125(KiCAD)
U2: PCM5102AQPWRQ1; SOP65P640X120-20N
U3: TPA6132A2RTET; QFN50P300X300X80-17N-D
U5: MCP1700x-330xxTT; SOT-23

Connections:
/+3V3: C5.1, C13.1, C14.1, C24.1, C25.1, C30.1, C31.1, C34.1, JP1.1 (A), JP2.1 (A), U1.23 (VDD_PADS1), U1.24 (VDD_PADS3_7), U2.1 (CPVDD), U2.8 (AVDD), U2.17 (XSMT), U2.20 (DVDD), U3.14 (VDD), U5.2 (VO)
/AMP_EN: R12.1, U1.54 (PIO[20](AMP_EN)), U3.13 (EN)
/CAPM: C15.2, U2.4 (CAPM)
/CAPP: C15.1, U2.2 (CAPP)
/D+: J2.A6 (D+), J2.B6 (D+), U1.9 (USB_DP)
/D-: J2.A7 (D-), J2.B7 (D-), U1.8 (USB_DN)
/GAIN0: JP1.2 (C), U3.6 (G0)
/GAIN1: JP2.2 (C), U3.7 (G1)
/HP_OUTL: J3.3, U3.16 (OUTL)
/HP_OUTR: J3.2, U3.5 (OUTR)
/I2S_LRCK: U1.4 (I2S_LRCK), U2.15 (LRCK)
/I2S_SCK: U1.5 (I2S_SCK), U2.13 (BCK)
/I2S_SDATA: U1.3 (I2S_SDATA/SPDIF_OUT), U2.14 (DIN)
/LP_OUTL: C21.1, C28.1, R10.2
/LP_OUTR: C22.1, C29.1, R11.2
/PCM_OUTL: R10.1, U2.6 (OUTL)
/PCM_OUTR: R11.1, U2.7 (OUTR)
/SGND_TRACE: J3.1, NT1.2, U3.15 (SGND)
/VBAT: C4.1, C8.1, C11.1, J6.1, R14.2, R15.2, SW1.1, U1.7 (VBAT_SENSE), U1.14 (VBAT), U5.3 (VI)
/VIN: C7.1, J2.A4 (VBUS), J2.A9 (VBUS), J2.B4 (VBUS), J2.B9 (VBUS), U1.10 (VCHG), U1.11 (VCHG_SENSE)
/VNEG: C16.2, U2.5 (VNEG)
GND: C4.2, C5.2, C7.2, C8.2, C11.2, C13.2, C14.2, C16.1, C17.2, C18.2, C24.2, C25.2, C26.2, C27.2, C28.2, C29.2, C30.2, C31.2, C32.2, C33.2, C34.2, J1.1, J2.A1 (GND), J2.A12 (GND), J2.B1 (GND), J2.B12 (GND), J2.SH (SHIELD), J6.2, JP1.3 (B), JP2.3 (B), NT1.1, R4.2, R5.2, R12.2, SW6.1, U1.15 (GND), U1.21 (GND), U1.38 (GND), U1.44 (GND), U1.45 (GND), U1.47 (GND), U2.3 (CPGND), U2.9 (AGND), U2.10 (DEMP), U2.11 (FLT), U2.12 (SCK), U2.16 (FMT), U2.19 (DGND), U3.2 (INL+), U3.3 (INR+), U3.10 (PGND), U3.17 (EP), U5.1 (GND)
unnamed: AE2.1 (A_1), C18.1, L1.2
unnamed: D4.2, R14.1
unnamed: D5.2, R15.1
unnamed: J1.2, U1.31 (PIO[2])
unnamed: J1.3, U1.26 (PIO[3])
unnamed: J1.4, U1.25 (PIO[4])
unnamed: J2.A5 (CC1), R4.1
unnamed: J2.B5 (CC2), R5.1
unnamed: D4.1, U1.16 (AIO[0]/LED[0])
unnamed: D5.1, U1.17 (AIO[1]/LED[1])
unnamed: C17.1, L1.1, U1.46 (ANT)
unnamed: SW1.2, U1.13 (SYS_CTRL)
unnamed: SW6.2, U1.32 (~RST/PIO[1])
unnamed: C26.1, C27.1, U2.18 (LDOO)
unnamed: C23.2, U3.9 (CPN)
unnamed: C23.1, U3.11 (CPP)
unnamed: C32.1, U3.12 (HPVDD)
unnamed: C33.1, U3.8 (HPVSS)
unnamed: C21.2, U3.1 (INL-)
unnamed: C22.2, U3.4 (INR-)

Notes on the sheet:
Left/Right Clock
Spannungspegel für GPIO und I2S
PCM Output Low Pass
LAYOUT KONZEPT: PARTITIONING Jeder GND-Pin bekommt direkt daneben ein eigenes Via Seperation der Analog und Digital Ströme durch platzierung
Disable Mute
X5R/X7R
Set "Normal Latency"
MCP1700: VBAT -> 3V3
CAPS: 100nF: Bauform 0805 (oder 0603), X7R, >= 16V 2.2nF: Bauform 0805 (oder 0603), X7R oder C0G/NP0 (C0G ist für Audio-Filter das absolut Beste, falls verfügbar!) 1μF & 2.2μF: Bauform 0805, X7R (oder X5R), >= 16V 10μF: Bauform 1206, X7R oder X5R, >= 16V
jumper
Internal 1.8V
Disable De-Emphasis
LAYOUT KONZEPT: SGND muss direkt bei der AUX-Buchse aufs GND Plane
PCM5102A: I2S -> Line Out L/R
Enable Interal PLL
Headphone Amplifier: PCM -> AUX
EWM104-BT5125(I2S) QCC5125

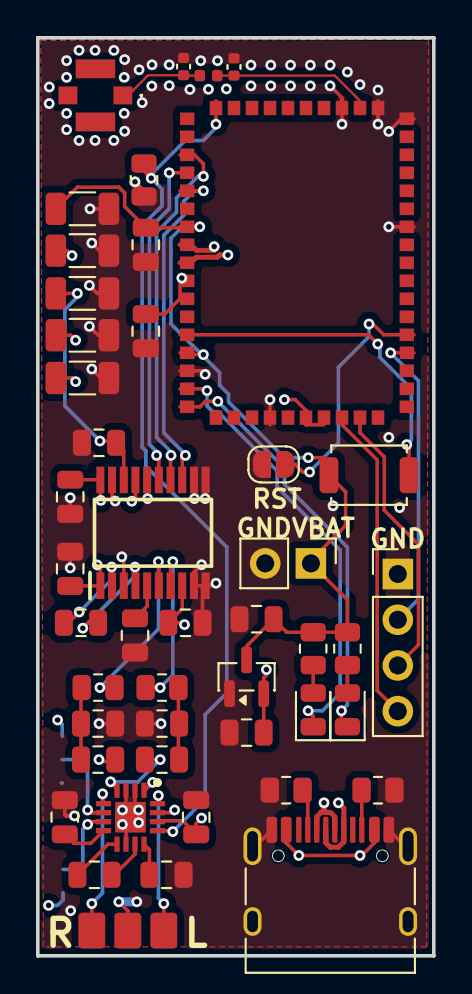
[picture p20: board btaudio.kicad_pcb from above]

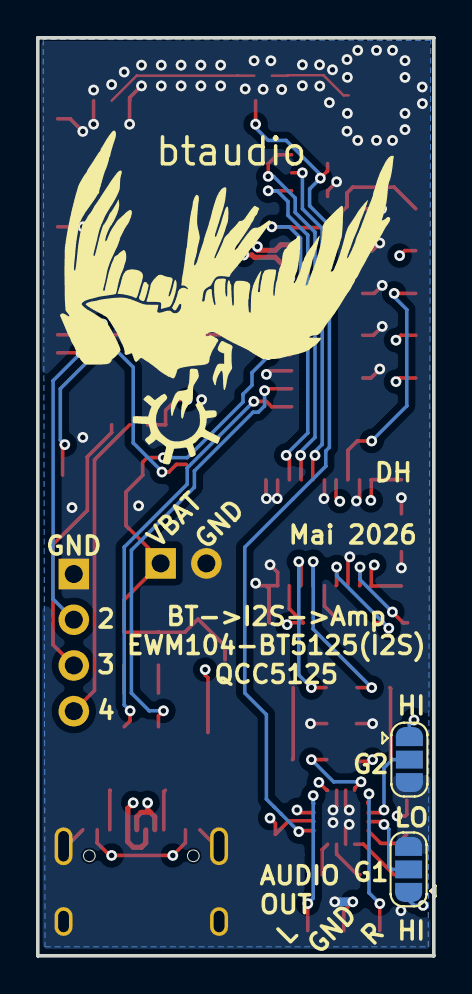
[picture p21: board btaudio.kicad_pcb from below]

Board: 4 copper layers, 22.0 x 51.0 mm, 49 parts (3 on the bottom side), 42 nets.

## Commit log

2026-05-07 some progress schema
    [btaudio.kicad_sch]
2026-05-09 PCM5102A Schema done
    [btaudio.kicad_sch]
2026-05-09 TPA6132A schema done
    [btaudio.kicad_sch]
2026-05-11 schema done
    [2450AT18A0100001E.stp, btaudio.kicad_sch]
2026-05-11 footprints assigned, img added
    [A-1JB.stp, btaudio.kicad_sch]
2026-05-11 bom & fix footprint
    [PJ320A-Pin-B.SLDPRT, PJ320A-Pin.SLDPRT, PJ320A.SLDASM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]
2026-05-14 started on layout
    [btaudio.kicad_pcb, btaudio.kicad_sch]
2026-05-14 compacting layout
    [btaudio.kicad_pcb, btaudio.kicad_sch]
2026-05-18 primary layout done
    [btaudio.kicad_pcb, btaudio.kicad_sch]
2026-05-18 layout almost done v1
    [btaudio.kicad_pcb]
2026-05-19 wiring done
    [btaudio.kicad_pcb]
2026-05-19 fixed 3d models
    [btaudio.kicad_pcb]
2026-05-19 finished layout & aesthetics
    [btaudio-B_Cu.gbr, btaudio-B_Mask.gbr, btaudio-B_Paste.gbr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]
2026-05-20 bom, img, prod files
    [btaudio.csv, btaudio.kicad_pcb]
